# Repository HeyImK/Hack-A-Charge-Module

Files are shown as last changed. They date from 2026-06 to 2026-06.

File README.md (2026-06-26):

# Hack-A-Charge IP5306 Charging and Power Board

A compact lithium battery charger and 5V boost module built around the IP5306 chip. It handles charging a single-cell lithium battery via USB-C and boosting the battery voltage up to a stable 5V output for external devices.

## Pictures

| Top View | Bottom View |
| :---: | :---: |
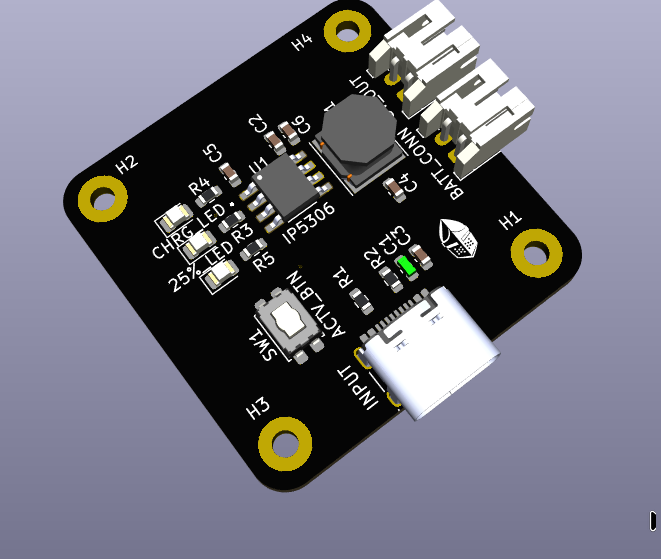
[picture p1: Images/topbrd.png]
Board Front
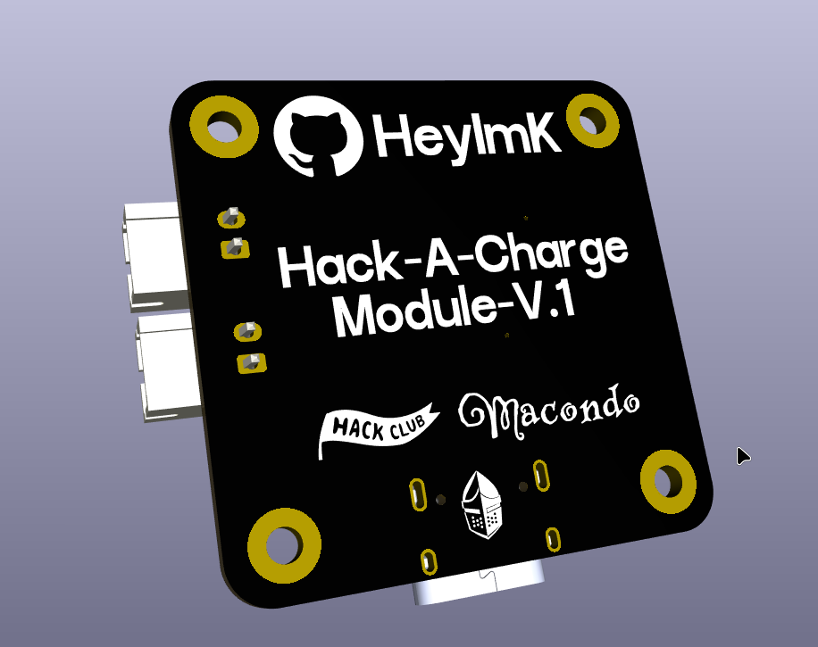
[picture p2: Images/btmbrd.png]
Board Back
|  |  |

## Features

* **Main Chip:** IP5306 handles both 2.1A battery charging and 2.4A synchronous 5V boosting.
* **Custom 3-LED Layout:** Configured with 3 specific status indicators showing Power Connected, Capacity >25%, and Capacity >75%.
* **Thermal Design:** Uses the ESOP-8 package with the exposed bottom power pad soldered directly to ground vias for cooling.
* **5V Output:** Solid 5V power line capable of supplying up to 2.1A to drive microcontrollers, displays, or peripherals.
* **Battery Connector:** Standard right-angle 2-pin JST-XH socket keeping the battery wire connection flat and low-profile.

## Core Components Used

* **Power Management IC:** Injoinic IP5306 
* **Power Inductor:** SWPA6045S1R0NT (1.0µH, 5.6A saturation current, 6x6x4.5mm SMD package)
* **Spike Filter:** Murata 0.1µF 50V X7R 0603 Ceramic Cap.
* **Indicators:** 0805 LEDs of different colours with 1kΩ resistors

| Circuit Schematic Design |
| :---: |
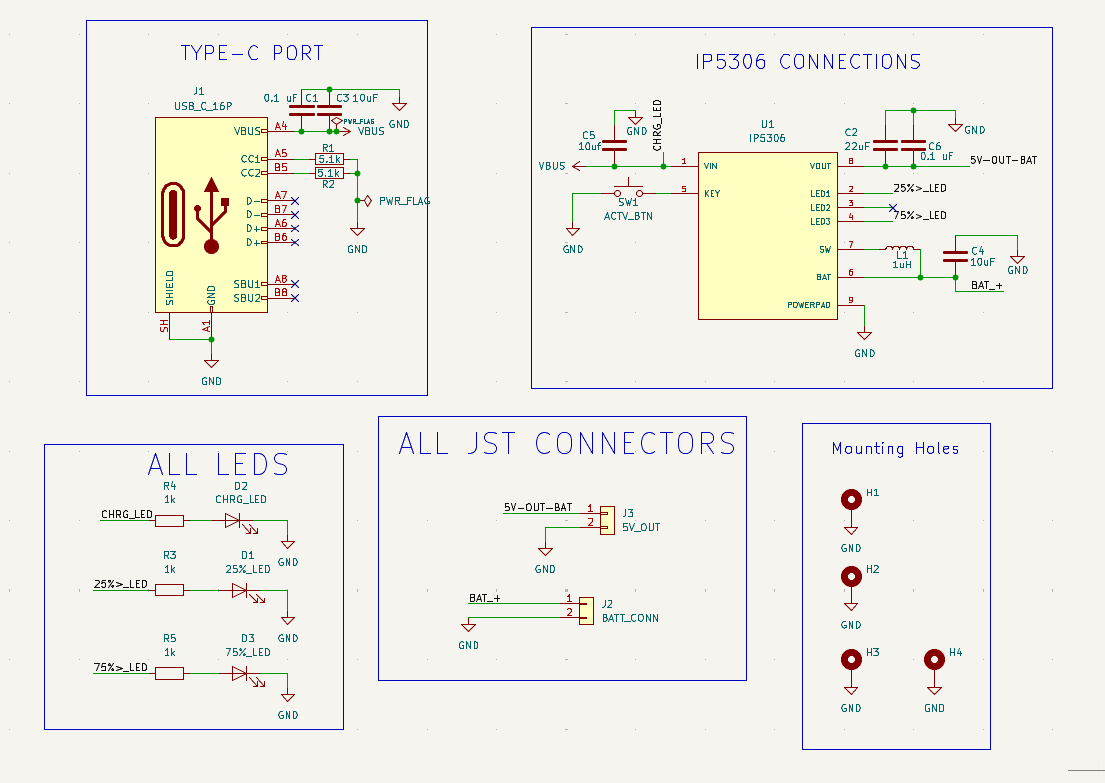
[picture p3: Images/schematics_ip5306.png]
Schematic Diagram
|  |

| PCB Top Layer Routing | PCB Bottom Layer Routing |
| :---: | :---: |
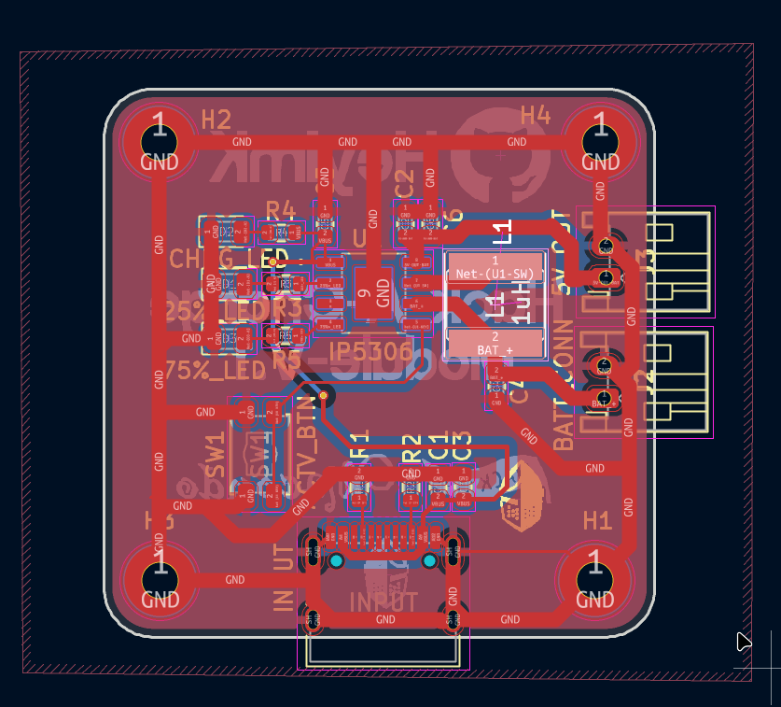
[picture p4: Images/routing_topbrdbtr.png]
Top Routing
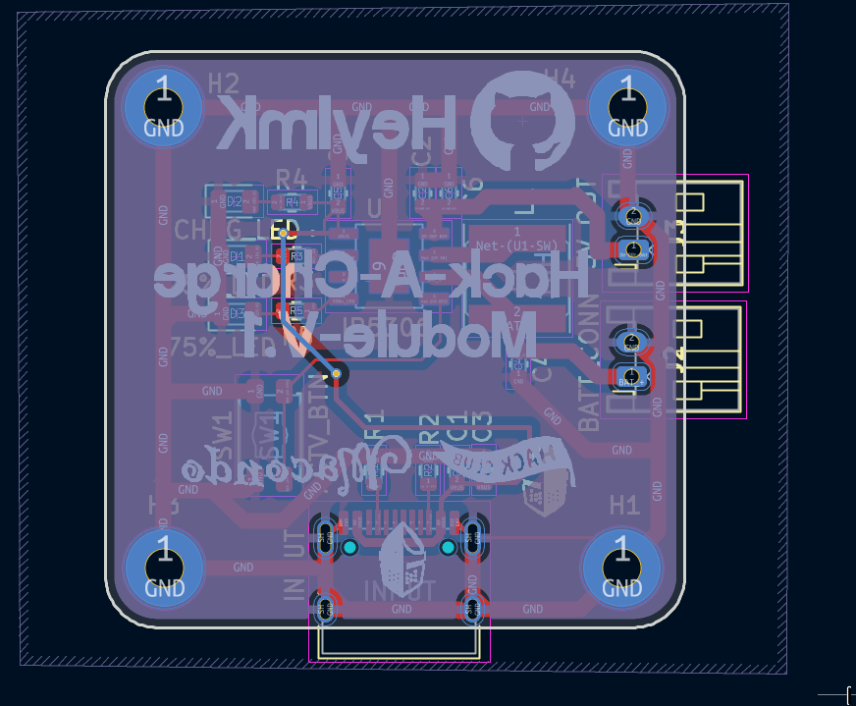
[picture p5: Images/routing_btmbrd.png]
Bottom Routing
|  |  |

### Connections
* **5V_OUT** 5V Output (at near 2.1 Amps) from the ip5306 in-built boost circuit.
* **BATT_CONN** The connector to connect the battery with the pcb for charging and output.
* **ACTV_BTN** For manual ON/OFF control and forced shut down and to check battery percentage when needed.

## License

This hardware project is open-source and licensed under the CERN Open Hardware Licence Version 2 - Strongly Reciprocal (CERN-OHL-S-2.0). 

You are free to copy, modify, distribute, and manufacture this board for personal or commercial use. However, if you modify these schematic or layout files and distribute your new design, you must release those modifications under this exact same CERN-OHL-S-2.0 license.

This design is shared without any warranty or implied guarantee. Check the LICENSE file for the full legal text.

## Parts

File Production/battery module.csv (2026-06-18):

Id | Designator | Footprint | Quantity | Designation | Supplier and ref
1 | C1, C6 | C_0603_1608Metric | 2 | 0.1 uF
2 | C2 | C_0603_1608Metric | 1 | 22uF
3 | C3, C4 | C_0603_1608Metric | 2 | 10uF
4 | C5 | C_0603_1608Metric | 1 | 10uf
5 | D1 | LED_0805_2012Metric | 1 | 25%_LED
6 | D2 | LED_0805_2012Metric | 1 | CHRG_LED
7 | D3 | LED_0805_2012Metric | 1 | 75%_LED
8 | INPUT | USB_C_Receptacle_HRO_TYPE-C-31-M-12 | 1 | USB_C_16P
9 | J2 | JST_PH_S2B-PH-K_1x02_P2.00mm_Horizontal | 1 | BATT_CONN
10 | J3 | JST_PH_S2B-PH-K_1x02_P2.00mm_Horizontal | 1 | 5V_OUT
11 | L1 | L_Taiyo-Yuden_NR-60xx | 1 | 1uH
12 | R1, R2 | R_0603_1608Metric | 2 | 5.1k
13 | R3, R4, R5 | R_0603_1608Metric | 3 | 1k
14 | SW1 | SW_SPST_EVQP2_ShortPushTravel_H2.1mm | 1 | ACTV_BTN
15 | U1 | SOP127P600X165-9N | 1 | IP5306

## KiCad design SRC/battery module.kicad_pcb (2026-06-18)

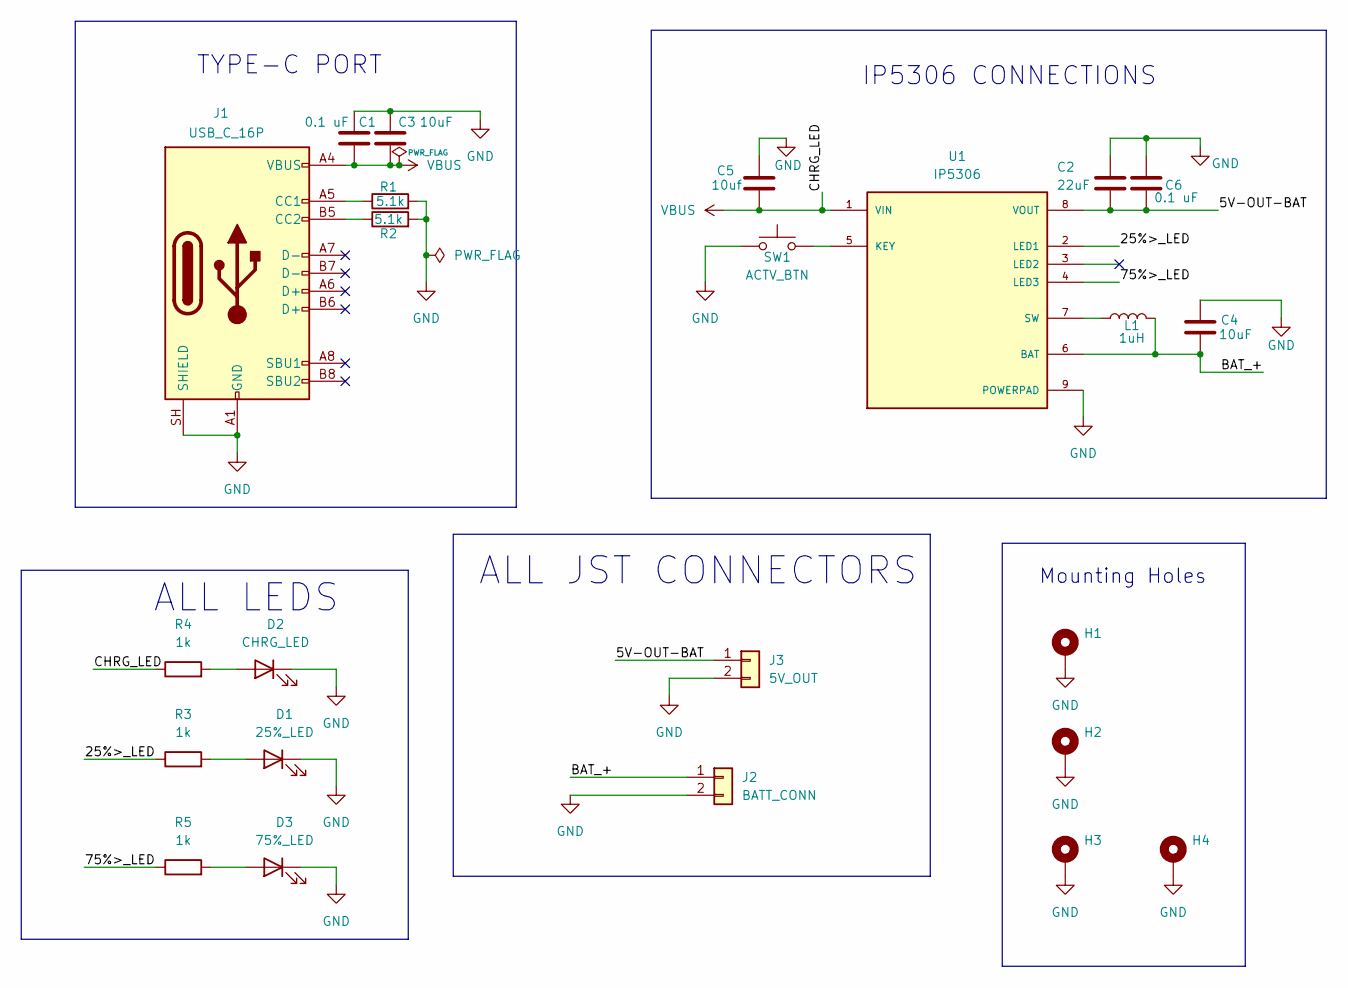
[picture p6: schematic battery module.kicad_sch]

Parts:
C1, C6: 0.1 uF; C_0603_1608Metric
C2: 22uF
C3, C4: 10uF
C5: 10uf
D1: 25%_LED; LED_0805_2012Metric
D2: CHRG_LED; LED_0805_2012Metric
D3: 75%_LED; LED_0805_2012Metric
H1, H2, H3, H4: Mount; MountingHole_2.2mm_M2_Pad
J1: USB_C_16P; USB_C_Receptacle_HRO_TYPE-C-31-M-12
J2: BATT_CONN; JST_PH_S2B-PH-K_1x02_P2.00mm_Horizontal
J3: 5V_OUT; JST_PH_S2B-PH-K_1x02_P2.00mm_Horizontal
L1: 1uH
R1, R2: 5.1k; R_0603_1608Metric
R3, R4, R5: 1k; R_0603_1608Metric
SW1: ACTV_BTN; SW_SPST_EVQP2_ShortPushTravel_H2.1mm
U1: IP5306; SOP127P600X165-9N; PARTREV 1.31

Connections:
/5V-OUT-BAT: C2.2, C6.2, J3.1, U1.8 (VOUT)
/25%>_LED: R3.1, U1.2 (LED1)
/75%>_LED: R5.1, U1.4 (LED3)
/BAT_+: C4.2, J2.1, L1.2, U1.6 (BAT)
GND: C1.1, C2.1, C3.1, C4.1, C5.1, C6.1, D1.1 (K), D2.1 (K), D3.1 (K), H1.1 (1_1), H2.1 (1_1), H3.1 (1_1), H4.1 (1_1), J1.A1 (GND), J1.A12 (GND), J1.B1 (GND), J1.B12 (GND), J1.SH (SHIELD), J2.2, J3.2, R1.2, R2.2, SW1.1, U1.9 (POWERPAD); also elsewhere on the board
unnamed: D1.2 (A), R3.2
unnamed: D2.2 (A), R4.2
unnamed: D3.2 (A), R5.2
unnamed 8: J1.A5 (CC1), R1.1; also elsewhere on the board
unnamed 9: J1.B5 (CC2), R2.1; also elsewhere on the board
unnamed: SW1.2, U1.5 (KEY)
unnamed: L1.1, U1.7 (SW)
VBUS: C1.2, C3.2, C5.2, J1.A4 (VBUS), J1.A9 (VBUS), J1.B4 (VBUS), J1.B9 (VBUS), R4.1, U1.1 (VIN); also elsewhere on the board

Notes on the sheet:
ALL JST CONNECTORS
Mounting Holes
ALL LEDS
IP5306 CONNECTIONS
TYPE-C PORT

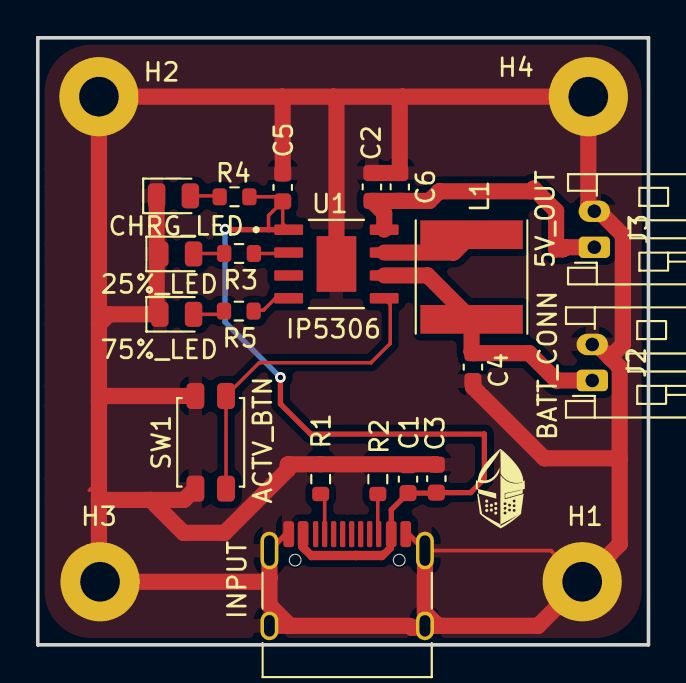
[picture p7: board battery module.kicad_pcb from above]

Board: 2 copper layers, 33.9 x 33.7 mm, 24 parts (0 on the bottom side), 13 nets.

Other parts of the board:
INPUT: USB_C_16P; USB_C_Receptacle_HRO_TYPE-C-31-M-12

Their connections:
GND: INPUT.A1 (GND), INPUT.A12 (GND), INPUT.B1 (GND), INPUT.B12 (GND), INPUT.SH (SHIELD); also elsewhere on the board
unnamed 8: INPUT.A5 (CC1); also elsewhere on the board
unnamed 9: INPUT.B5 (CC2); also elsewhere on the board
VBUS: INPUT.A4 (VBUS), INPUT.A9 (VBUS), INPUT.B4 (VBUS), INPUT.B9 (VBUS); also elsewhere on the board
